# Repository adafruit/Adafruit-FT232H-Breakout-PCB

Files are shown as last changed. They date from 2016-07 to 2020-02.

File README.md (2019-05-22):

## Adafruit FT232H Breakout PCB
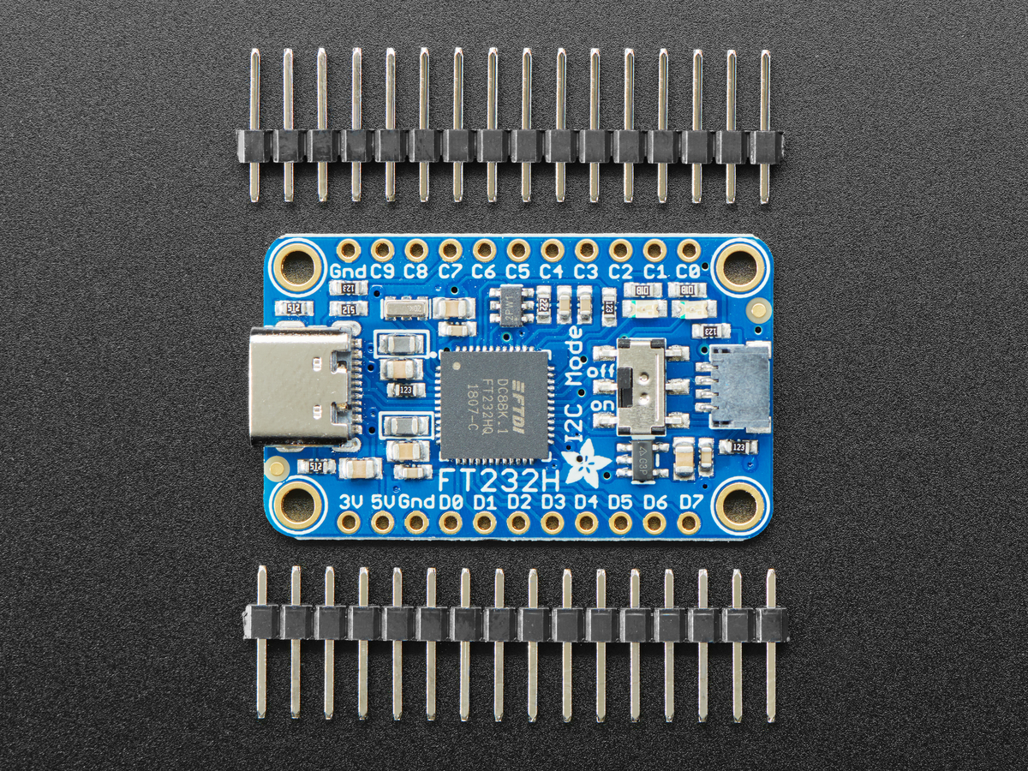
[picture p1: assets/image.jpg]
<a href="http://www.adafruit.com/products/2264"><br/>
Click here to purchase one from the Adafruit shop</a>

Wouldn't it be cool to drive a tiny OLED display, read a color sensor, or even just flash some LEDs directly from your computer?  Sure you can program an Arduino or Trinket to talk to these devices and your computer, but why can't your computer just talk to those devices and sensors itself?  Well, now your computer can talk to devices using the Adafruit FT232H breakout board!

What can the FT232H chip do?  This chip from FTDI is similar to their USB to serial converter chips but adds a 'multi-protocol synchronous serial engine' which allows it to speak many common protocols like SPI, I2C, serial UART, JTAG, and more!  There's even a handful of digital GPIO pins that you can read and write to do things like flash LEDs, read switches or buttons, and more.  The FT232H breakout is like adding a little swiss army knife for serial protocols to your computer!

PCB files for the Adafruit FT232H Breakout. The format is EagleCAD schematic and board layout
- http://www.adafruit.com/products/2264

### License

Adafruit invests time and resources providing this open source design, please support Adafruit and open-source hardware by purchasing products from [Adafruit](https://www.adafruit.com)!

All text above must be included in any redistribution

Designed by Limor Fried/Ladyada for Adafruit Industries.
Creative Commons Attribution/Share-Alike, all text above must be included in any redistribution. 
See license.txt for additional information.

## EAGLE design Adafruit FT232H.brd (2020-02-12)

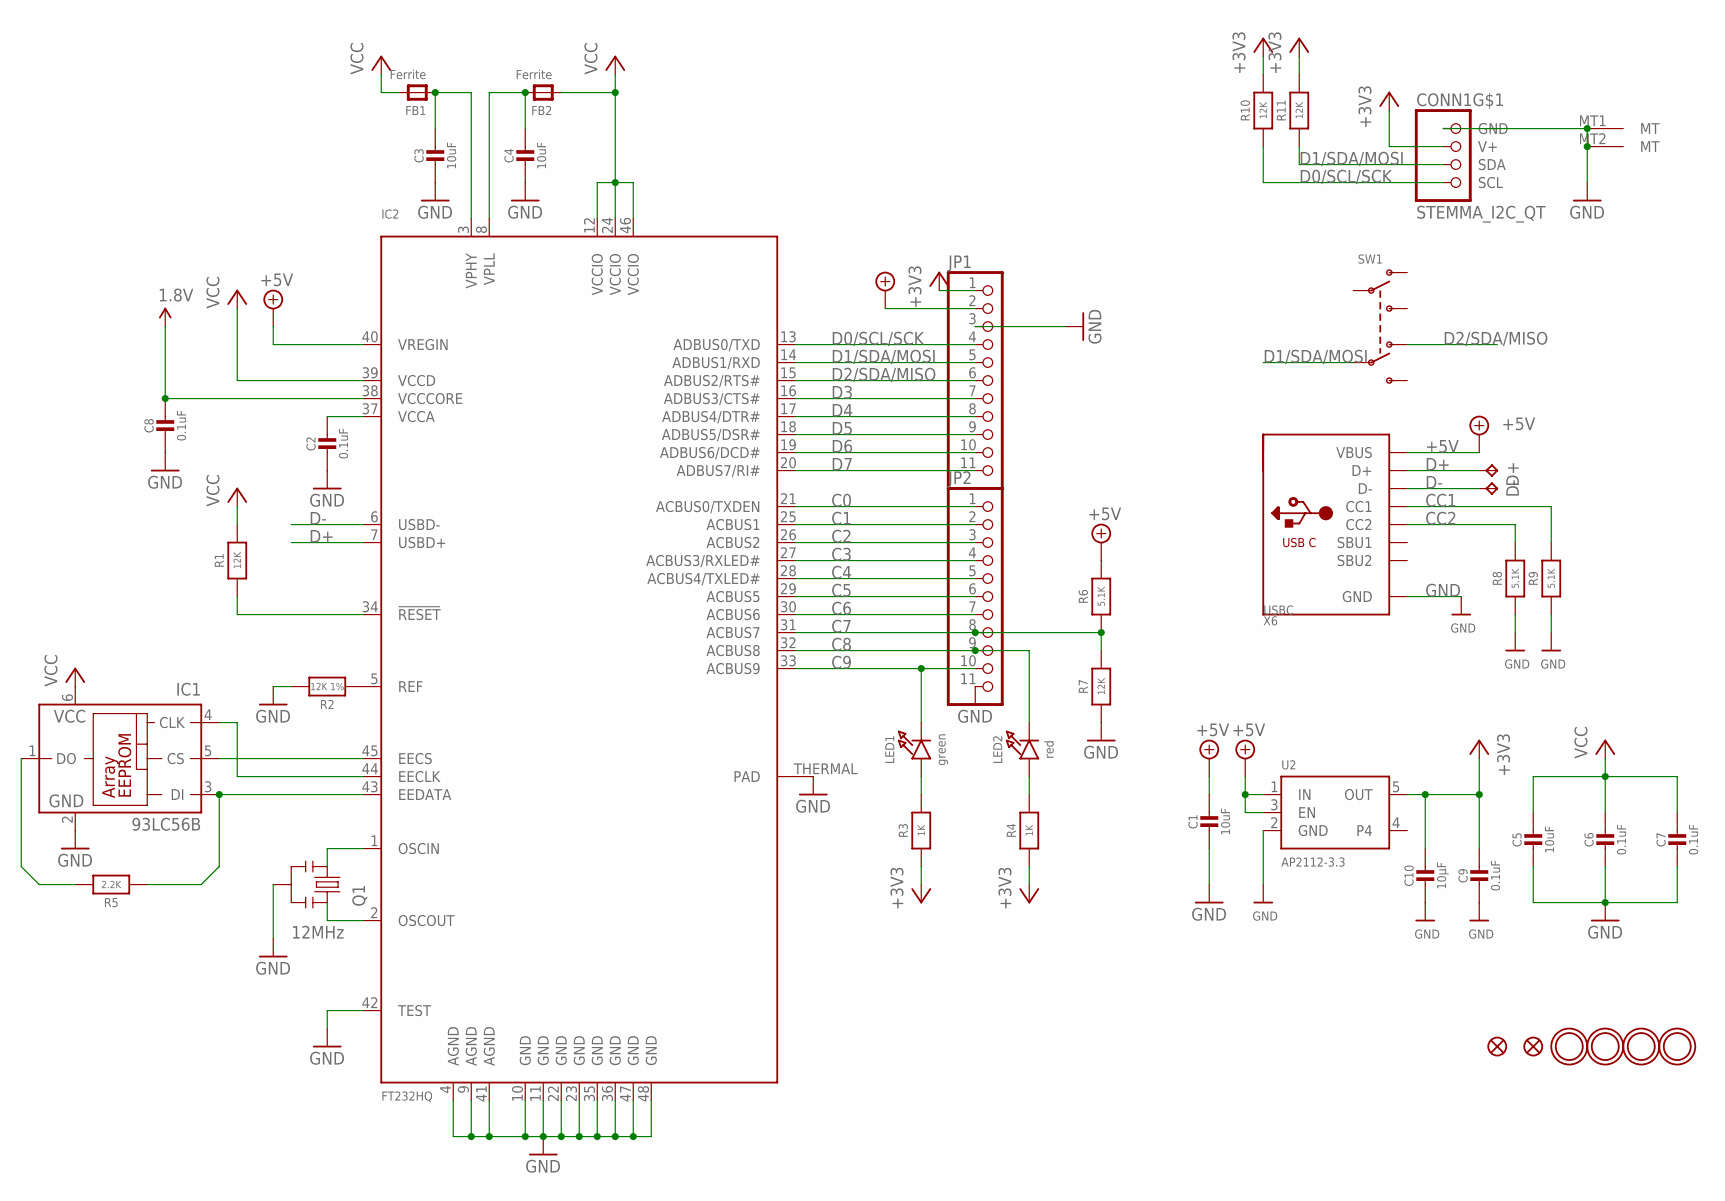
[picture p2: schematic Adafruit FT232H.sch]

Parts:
C1, C3, C4, C5: 10uF; 0805-NO
C2, C6, C7, C8, C9: 0.1uF; 0603-NO
C10: 10µF; 0805-NO
CONN1: STEMMA_I2C_QT; JST_SH4
D+: TPTP17R; TP17R
D-: TPTP17R; TP17R
FB1, FB2: Ferrite; _0805
FID1, FID2: FIDUCIAL""; FIDUCIAL_1MM
IC1: 93LC56B; SOT23-6
IC2: FT232HQ; QFN48_8MM
JP1, JP2: HEADER-1X11; 1X11_ROUND
LED1: green; CHIPLED_0805_NOOUTLINE
LED2: red; CHIPLED_0805_NOOUTLINE
Q1: 12MHz; RESONATOR-SMD
R1, R7, R10, R11: 12K; 0603-NO
R2: 12K 1%; 0603-NO
R3, R4: 1K; 0603-NO
R5: 2.2K; 0603-NO
R6, R8, R9: 5.1K; 0603-NO
SW1: SWITCH_DPDTEG1390; EG1390
U2: AP2112-3.3; SOT23-5
U$4, U$5, U$6, U$7: MOUNTINGHOLE2.5; MOUNTINGHOLE_2.5_PLATED
X6: USBC; USB_C_CUSB31-CFM2AX-01-X

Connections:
1.8V: C8.1, IC2.38 (VCCCORE)
+3V3: C9.1, C10.1, CONN1.2 (V+), JP1.1, R3.1, R4.1, R10.2, R11.2, U2.5 (OUT)
+5V: C1.1, IC2.40 (VREGIN), JP1.2, R6.2, U2.1 (IN), U2.3 (EN), X6.A4B9 (VBUS), X6.B4A9 (VBUS)
C0: IC2.21 (ACBUS0/TXDEN), JP2.1
C1: IC2.25 (ACBUS1), JP2.2
C2: IC2.26 (ACBUS2), JP2.3
C3: IC2.27 (ACBUS3/RXLED#), JP2.4
C4: IC2.28 (ACBUS4/TXLED#), JP2.5
C5: IC2.29 (ACBUS5), JP2.6
C6: IC2.30 (ACBUS6), JP2.7
C7: IC2.31 (ACBUS7), JP2.8, R6.1, R7.2
C8: IC2.32 (ACBUS8), JP2.9, LED2.C
C9: IC2.33 (ACBUS9), JP2.10, LED1.C
CC1: R9.2, X6.A5 (CC1)
CC2: R8.2, X6.B5 (CC2)
D0/SCL/SCK: CONN1.4 (SCL), IC2.13 (ADBUS0/TXD), JP1.4, R10.1
D1/SDA/MOSI: CONN1.3 (SDA), IC2.14 (ADBUS1/RXD), JP1.5, R11.1, SW1.P2
D2/SDA/MISO: IC2.15 (ADBUS2/RTS#), JP1.6, SW1.O2
D3: IC2.16 (ADBUS3/CTS#), JP1.7
D4: IC2.17 (ADBUS4/DTR#), JP1.8
D5: IC2.18 (ADBUS5/DSR#), JP1.9
D6: IC2.19 (ADBUS6/DCD#), JP1.10
D7: IC2.20 (ADBUS7/RI#), JP1.11
D+: D+.TP, IC2.7 (USBD+), X6.A6 (D+), X6.B6 (D+)
D-: D-.TP, IC2.6 (USBD-), X6.A7 (D-), X6.B7 (D-)
GND: C1.2, C2.2, C3.2, C4.2, C5.2, C6.2, C7.2, C8.2, C9.2, C10.2, CONN1.1 (GND), CONN1.MT1 (MT), CONN1.MT2 (MT), IC1.2 (GND), IC2.4 (AGND), IC2.9 (AGND), IC2.10 (GND), IC2.11 (GND), IC2.22 (GND), IC2.23 (GND), IC2.35 (GND), IC2.36 (GND), IC2.41 (AGND), IC2.42 (TEST), IC2.47 (GND), IC2.48 (GND), IC2.THERMAL (PAD), JP1.3, JP2.11, Q1.2, R2.2, R7.1, R8.1, R9.1, U2.2 (GND), X6.A1B12 (GND), X6.B1A12 (GND)
unnamed: IC2.1 (OSCIN), Q1.1
unnamed: IC2.2 (OSCOUT), Q1.3
unnamed: IC2.5 (REF), R2.1
unnamed: LED2.A, R4.2
unnamed: IC2.34 (!RESET), R1.1
unnamed: LED1.A, R3.2
unnamed: IC1.3 (DI), IC2.43 (EEDATA), R5.1
unnamed: IC1.5 (CS), IC2.45 (EECS)
unnamed: IC1.4 (CLK), IC2.44 (EECLK)
unnamed: IC1.1 (DO), R5.2
VCC: C5.1, C6.1, C7.1, FB1.2, FB2.1, IC1.6 (VCC), IC2.12 (VCCIO), IC2.24 (VCCIO), IC2.39 (VCCD), IC2.46 (VCCIO), R1.2
VCCA: C2.1, IC2.37 (VCCA)
VPHY: C3.1, FB1.1, IC2.3 (VPHY)
VPLL: C4.1, FB2.2, IC2.8 (VPLL)

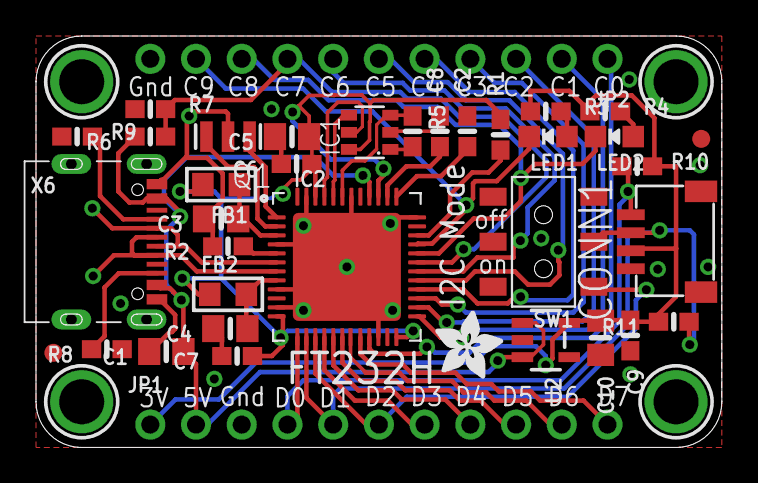
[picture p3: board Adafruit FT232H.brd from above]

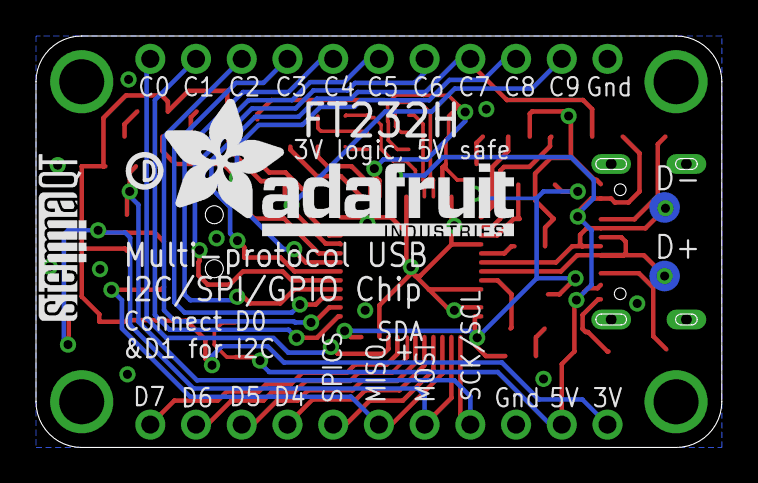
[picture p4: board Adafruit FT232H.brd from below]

Board: 2 copper layers, 38.1 x 22.9 mm, 46 parts (5 on the bottom side), 40 nets.

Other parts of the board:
U$2: ADAFRUIT_3.5MM
U$3: ADAFRUIT_TEXT_20MM
U$8: STEMMAQT
U$11: PCBFEAT-REV-040

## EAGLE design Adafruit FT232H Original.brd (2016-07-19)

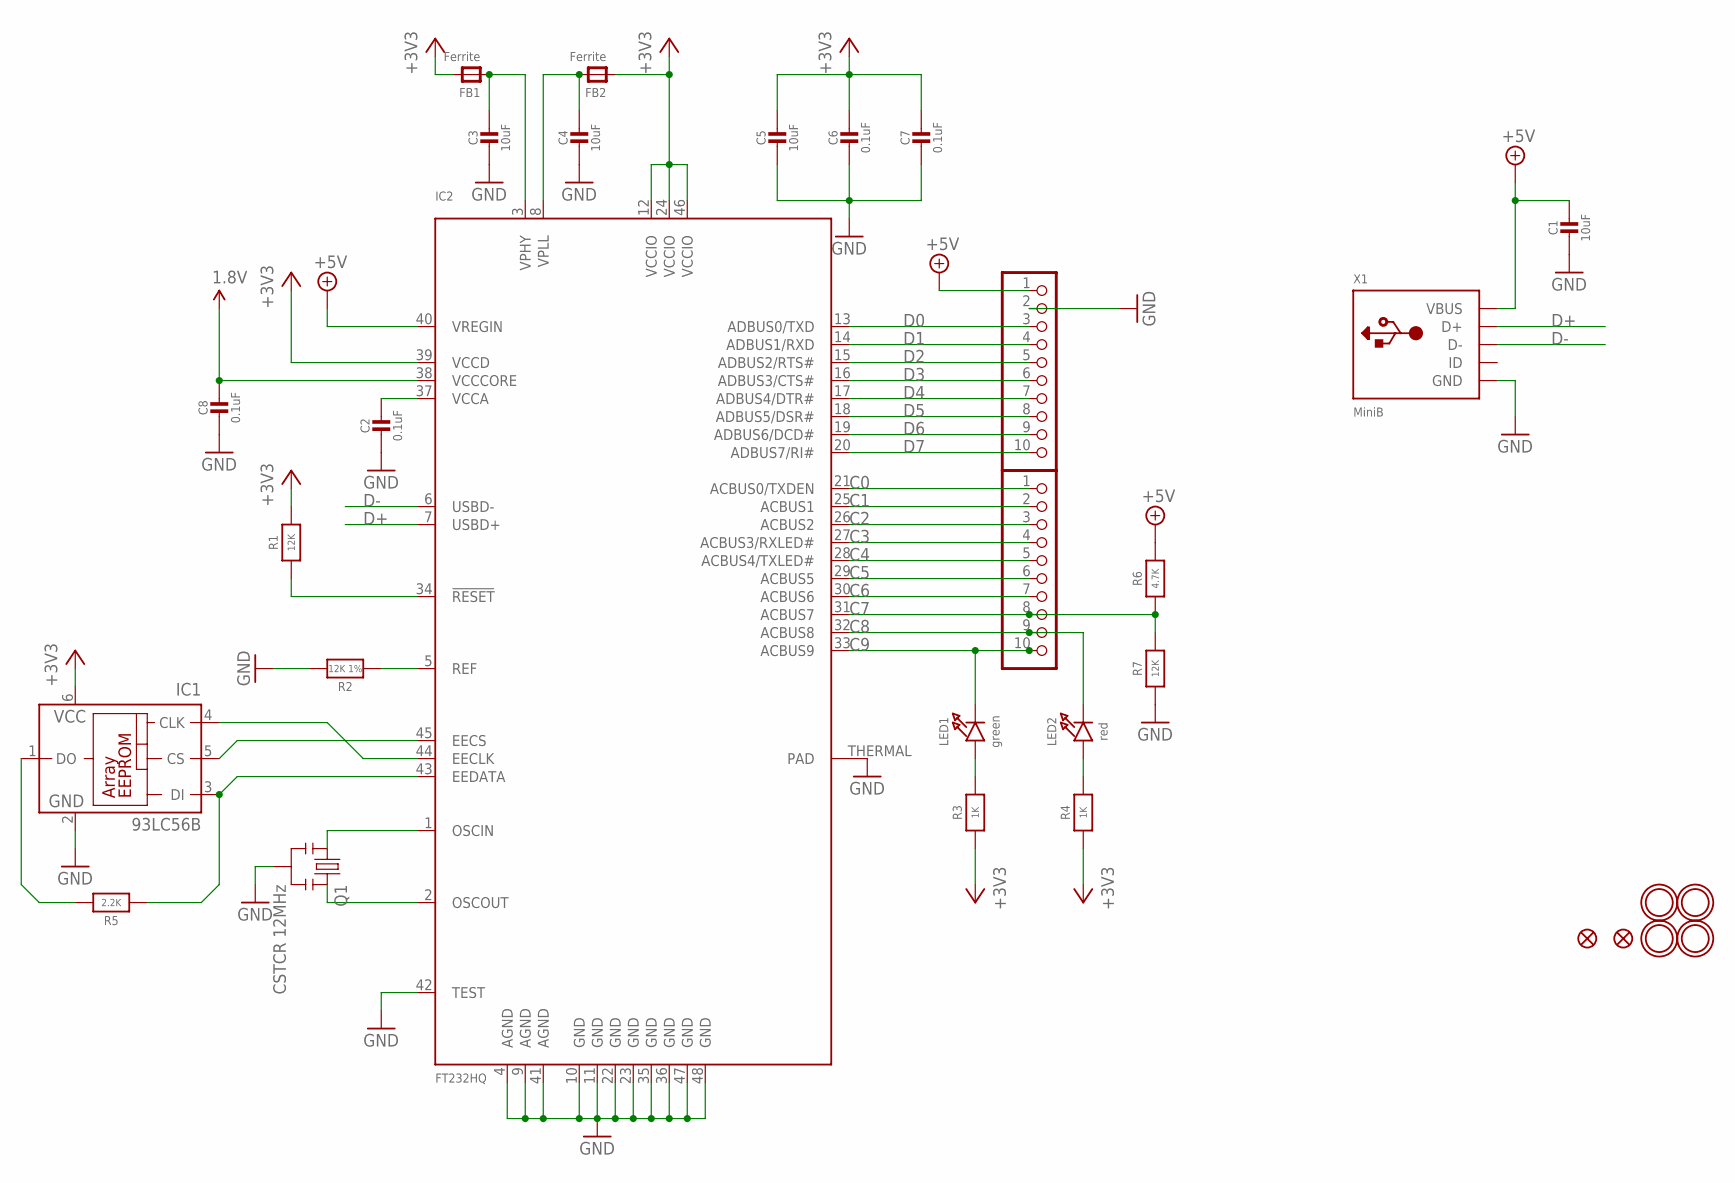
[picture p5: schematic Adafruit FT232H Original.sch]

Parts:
C1, C3, C4, C5: 10uF; 0805-NO
C2, C6, C7, C8: 0.1uF; 0805-NO
FB1, FB2: Ferrite; _0805
FID1, FID2: FIDUCIAL""; FIDUCIAL_1MM
IC1: 93LC56B; SOT23-6
IC2: FT232HQ; QFN48_8MM
LED1: green; CHIPLED_0805_NOOUTLINE
LED2: red; CHIPLED_0805_NOOUTLINE
Q1: CSTCR 12MHz; RESONATOR-SMD
R1, R7: 12K; 0805-NO
R2: 12K 1%; 0805-NO
R3, R4: 1K; 0805-NO
R5: 2.2K; _0805MP
R6: 4.7K; 0805-NO
U$2, U$3: PINHD-1X10; 1X10-BIG
U$4, U$5, U$6, U$7: MOUNTINGHOLE2.5; MOUNTINGHOLE_2.5_PLATED
X1: MiniB; 4UCONN_20329

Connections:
1.8V: C8.1, IC2.38 (VCCCORE)
+3V3: C5.1, C6.1, C7.1, FB1.2, FB2.1, IC1.6 (VCC), IC2.12 (VCCIO), IC2.24 (VCCIO), IC2.39 (VCCD), IC2.46 (VCCIO), R1.2, R3.1, R4.1
+5V: C1.1, IC2.40 (VREGIN), R6.2, U$2.1, X1.VBUS
C0: IC2.21 (ACBUS0/TXDEN), U$3.1
C1: IC2.25 (ACBUS1), U$3.2
C2: IC2.26 (ACBUS2), U$3.3
C3: IC2.27 (ACBUS3/RXLED#), U$3.4
C4: IC2.28 (ACBUS4/TXLED#), U$3.5
C5: IC2.29 (ACBUS5), U$3.6
C6: IC2.30 (ACBUS6), U$3.7
C7: IC2.31 (ACBUS7), R6.1, R7.2, U$3.8
C8: IC2.32 (ACBUS8), LED2.C, U$3.9
C9: IC2.33 (ACBUS9), LED1.C, U$3.10
D0: IC2.13 (ADBUS0/TXD), U$2.3
D1: IC2.14 (ADBUS1/RXD), U$2.4
D2: IC2.15 (ADBUS2/RTS#), U$2.5
D3: IC2.16 (ADBUS3/CTS#), U$2.6
D4: IC2.17 (ADBUS4/DTR#), U$2.7
D5: IC2.18 (ADBUS5/DSR#), U$2.8
D6: IC2.19 (ADBUS6/DCD#), U$2.9
D7: IC2.20 (ADBUS7/RI#), U$2.10
D+: IC2.7 (USBD+), X1.D+
D-: IC2.6 (USBD-), X1.D-
GND: C1.2, C2.2, C3.2, C4.2, C5.2, C6.2, C7.2, C8.2, IC1.2 (GND), IC2.4 (AGND), IC2.9 (AGND), IC2.10 (GND), IC2.11 (GND), IC2.22 (GND), IC2.23 (GND), IC2.35 (GND), IC2.36 (GND), IC2.41 (AGND), IC2.42 (TEST), IC2.47 (GND), IC2.48 (GND), IC2.THERMAL (PAD), Q1.2, R2.2, R7.1, U$2.2, X1.BASE@1 (GND), X1.BASE@2 (GND), X1.GND, X1.SPRT@1 (GND), X1.SPRT@2 (GND), X1.SPRT@3 (GND), X1.SPRT@4 (GND)
unnamed: IC2.1 (OSCIN), Q1.1
unnamed: IC2.2 (OSCOUT), Q1.3
unnamed: IC2.5 (REF), R2.1
unnamed: LED2.A, R4.2
unnamed: IC2.34 (!RESET), R1.1
unnamed: LED1.A, R3.2
unnamed: IC1.3 (DI), IC2.43 (EEDATA), R5.1
unnamed: IC1.5 (CS), IC2.45 (EECS)
unnamed: IC1.4 (CLK), IC2.44 (EECLK)
unnamed: IC1.1 (DO), R5.2
VCCA: C2.1, IC2.37 (VCCA)
VPHY: C3.1, FB1.1, IC2.3 (VPHY)
VPLL: C4.1, FB2.2, IC2.8 (VPLL)

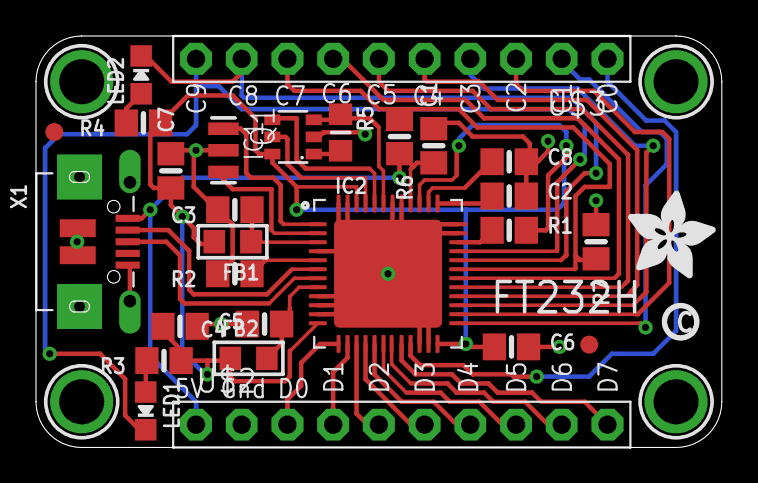
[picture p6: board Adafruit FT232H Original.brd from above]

Board: 2 copper layers, 38.1 x 22.9 mm, 34 parts (1 on the bottom side), 37 nets.

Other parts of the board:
U$8: ADAFRUIT_5MM
U$9: ADAFRUIT_TEXT_30MM
U$11: PCBFEAT-REV-040

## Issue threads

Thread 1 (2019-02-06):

libftdi installation - python version

Claire06, 2019-02-06:
Hello everyone,

I am following the instructions on https://learn.adafruit.com/adafruit-ft232h-breakout/windows-setup
to install the ftdi library on my computer and I am getting errors when importing the ftdi1. It is written to use python2.7 but as it hasn't been updated since 2014 I am trying with python3.6. Do you think that my error is because I am using python3.6 or should this version of python be supported?

Thank you very much,

Claire

ladyada, 2019-10-09:
hiya check the new guide at https://learn.adafruit.com/circuitpython-on-any-computer-with-ft232h

Closed 2019-10-09.

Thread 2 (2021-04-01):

Version 2 Silk screen vs Schematic +5 +3 backwards

K2AAE, 2021-04-01:
The silkscreen on version 2 PCB shows pin 1=3V pin 2=5V - which matches the eagle AdafruitFT232H.sch
The schematic at https://learn.adafruit.com/assets/88382
shows pin 1 an up arrow, what ever that means, pin 2 as 3V

ladyada, 2021-04-01:
hi, you are not reading the schematic completely - there is no error.

Closed 2021-04-01.

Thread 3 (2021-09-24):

Confusing label on V2 Breakout

caternuson, 2021-09-24:
Mentioned here:
https://forums.adafruit.com/viewtopic.php?f=8&t=183096

Suppose to be D1 and D2? Maybe don't even need this? Can just use the mode switch. And then ref the pinouts?
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

ladyada, 2021-09-24:
oh yeah, cna fix on next pcb run. for now they should just close the switch

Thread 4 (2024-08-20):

Looking for the original firmware

3dprogramin, 2024-08-20:
I just bought the device from a vendor. It looks like the real deal, cost wise (more costly), has the Adafruit logo, has the QC stamp on it, PCB looks solid, etc. The only reason that makes me think it might be fake is that I had some issues with it on Linux with PulseView, with the ftdi-la driver to be more precise:
`sr: [00:00.018366] ftdi-la: Failed to get the FTDI strings: -7`

Searching on google I found that somebody else had the same issue.
The guy fixed it by flashing a different firmware, more about it [here](https://www.mail-archive.com/sigrok-devel@lists.sourceforge.net/msg03760.html)
I downloaded that firmware, inspected it with xxd and uploaded it.

The firmware is really small, 256 bytes:
```
00000000: 1000 0304 1460 0009 e000 0000 0000 a014  .....`..........
00000010: b42a de0c 0000 0000 0000 0000 0000 0000  .*..............
00000020: 0000 0000 0000 0000 0000 0000 0000 0000  ................
00000030: 0000 0000 0000 0000 0000 0000 0000 0000  ................
00000040: 0000 0000 0000 0000 0000 0000 0000 0000  ................
00000050: 0000 0000 0000 0000 0000 0000 0000 0000  ................
00000060: 0000 0000 0000 0000 0000 0000 0000 0000  ................
00000070: 0000 0000 0000 0000 0000 0000 0000 0000  ................
00000080: 0000 0000 0000 0000 0000 0000 0000 0000  ................
00000090: 0000 0000 0000 0000 0000 0000 0000 0000  ................
000000a0: 1403 4100 6300 6d00 6500 2000 4900 6e00  ..A.c.m.e. .I.n.
000000b0: 6300 2e00 2a03 5500 5300 4200 2000 5300  c...*.U.S.B. .S.
000000c0: 6500 7200 6900 6100 6c00 2000 4300 6f00  e.r.i.a.l. .C.o.
000000d0: 6e00 7600 6500 7200 7400 6500 7200 0c03  n.v.e.r.t.e.r...
000000e0: 3000 3800 2d00 3100 3500 0203 0000 0000  0.8.-.1.5.......
000000f0: 0000 0000 0000 0000 0000 0000 0000 ad20  ...............
```

Now my device does work with PulseView but the LED on the device isn't working anymore.
Because the LED doesn't work, I don't know what else might not work as it's supposed to.
I kind of messed up because I didn't read the contents of the flash before uploading this firmware.

Is there any chance to upload the original firmware to this repository?
Much appreciated !

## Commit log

2020-02-12 Rename file.
    [Adafruit FT232H Original.brd]
2020-02-12 Add updated board files.
    [Adafruit FT232H.brd, Adafruit FT232H.sch]

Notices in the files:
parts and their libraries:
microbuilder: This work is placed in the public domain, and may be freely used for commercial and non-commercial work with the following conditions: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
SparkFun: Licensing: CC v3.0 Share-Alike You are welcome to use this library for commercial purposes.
